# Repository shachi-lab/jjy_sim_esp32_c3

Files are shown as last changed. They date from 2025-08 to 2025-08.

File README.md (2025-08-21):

# 📡 JJY Simulator for ESP32-C3

電波時計の補正信号をESP32-C3で自作！
NTPから取得した正確な時刻をもとに、40kHz / 60kHz のJJY信号をPWM出力で模倣する、ミニJJYシミュレーターです。

## 🛠 特徴

- ESP32-C3 + Arduino によるコンパクトな構成
- Wi-Fi設定はボタンひとつで簡単APモード
- OLEDに現在時刻を表示
- PWM出力は GPIO10 から
- JJY 40kHz（東日本）/ 60kHz（西日本）を切り替え可能
- 出力信号は基板内蔵の簡易アンテナから放射

<a href="./images/jjy_sim_board_w800.jpg">
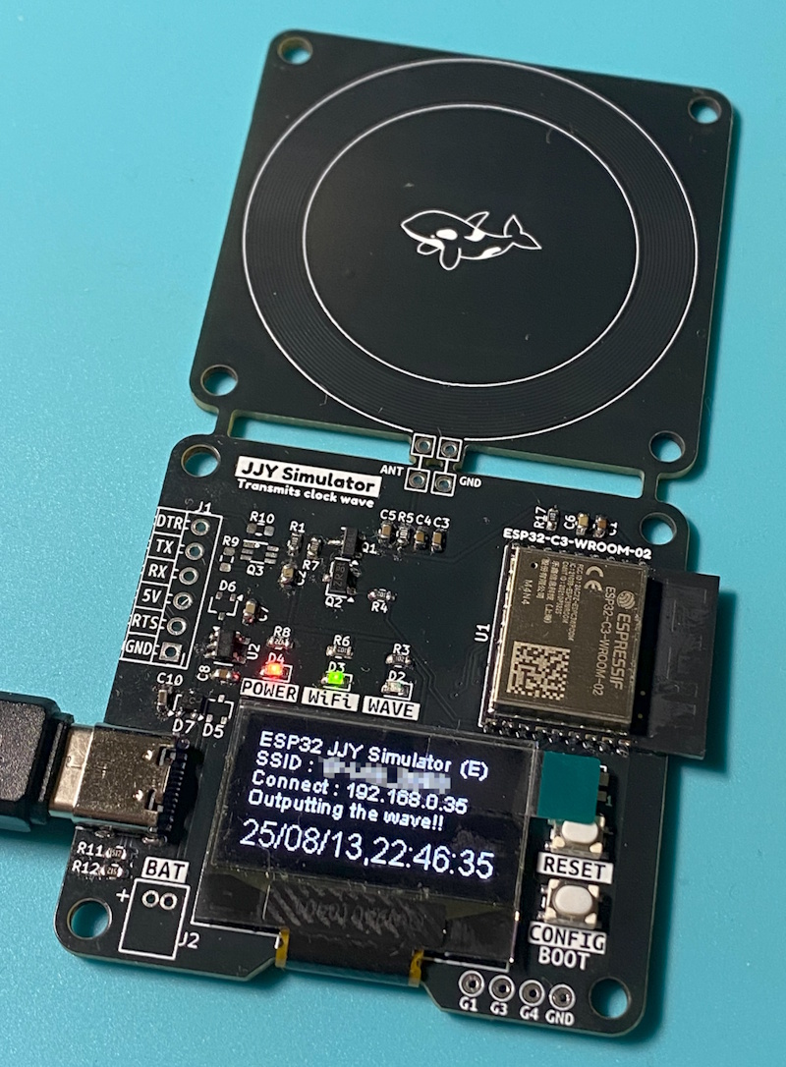
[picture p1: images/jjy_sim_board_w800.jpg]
JJYシミュレーター
</a><br/>

## ⚙️ 使用方法

### 1. コンパイル・書き込み

1. Arduino IDE で ESP32ボードを有効にする  
   - ボードマネージャURL：`https://dl.espressif.com/dl/package_esp32_index.json`
   - 対象ボード：**ESP32-C3 Dev Module**

2. 必要なライブラリをインストールする  
   - [WiFiManager](https://github.com/tzapu/WiFiManager)（バージョン 2.0.17 推奨）
   - [ESP8266 and ESP32 OLED driver for SSD1306 displays](https://github.com/ThingPulse/esp8266-oled-ssd1306)（バージョン 4.6.0 推奨）

   ※ Arduino IDE の「ライブラリを管理」メニューからインストール可能です。

3. `JJY_Sim_ESP32_C3.ino` を開き、必要に応じて以下を編集：
   - `#define JJY_TYPE 0` → `0: 40kHz`, `1: 60kHz`

4. 書き込みポートとボード設定を確認して、コンパイル＆アップロード

> 💡 補足：
> ESP32-C3は、外付けのUSBシリアルICを使わず、チップ内蔵の**ネイティブUSB-UART**機能で書き込み・シリアル通信を行います。
> 一部の環境（特にWindows）では、デバイス認識のために**Espressif提供のUSBドライバ**が必要になる場合があります。

- ドライバDLページ 👉 https://www.espressif.com/en/support/download/other-tools

>⚠️ 初回起動について
> プログラムを書き込んだ直後の「初回起動」では、内部FLASHにファイルシステムを構築する処理が行われます。  
> このため、数十秒ほど反応がなく「ハングしたように見える」場合があります。  
> 完了すると自動的に再起動し、以降は通常通りすぐに動作しますが、再起動しない場合は、RESETボタンでリセットしてください。

### 2. Wi-Fi設定

- 電源投入 or リセット後、5秒以内に CONFIGスイッチを押す
- `ESP32_XXXXXXXX` というAPが起動（パスキー：`password`）
- スマホやPCから接続 → キャプティブポータルでSSID/パスキーを設定

### 3. 動作確認

- 電源投入 or リセット後、5秒間放置すると、WiFiのAPに接続しに行きます。
- APに接続すると、NTPサーバーから時刻を取得します。
- OLEDに現在時刻が表示され、0秒からPWMでJJY信号出力開始
- 電波時計の「受信ボタン」を押して、近くに置いておくだけ！

## 🔌 ピンアサイン（主なもの）

| 機能 | GPIO | 備考 |
|---|---|---|
| JJY PWM出力 | 10 | 変調された信号を出力 |
| CONFIGスイッチ | 9 | Wi-Fi設定用（**BOOTピンと兼用**） |
| ACT LED | 5 | 動作中LED |
| IND LED | 0 | 状態表示用LED（共用可） |
| OLED Reset | 2 | OLEDモジュールリセット |
| OLED SDA|7| OLED I2C データー|
| OLED SCL |6|OLED I2C クロック|

## 🧾 ファイル構成

```
JJY_Sim_ESP32_C3.ino       // メインスケッチ
wire_compat.h              // ESP32-C3 用の I2C バス互換ヘッダ
```

## 📎 依存ライブラリ

- [WiFiManager](https://github.com/tzapu/WiFiManager)
- [ESP8266 and ESP32 OLED driver](https://github.com/ThingPulse/esp8266-oled-ssd1306)

## 🔗 関連リンク

- ブログ記事（詳細解説＋ケースや基板配布）  
  👉 https://blog.shachi-lab.com/033_jjy_simulator/

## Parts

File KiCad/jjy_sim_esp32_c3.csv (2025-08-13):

Reference | Value | Footprint | Qty
C1,C3,C4,C5,C9 | 0.1u | Capacitor SMD 1608 | 5
C2,C7,C10,C11,C12,C13,C14 | 1u | Capacitor SMD 1608 | 7
C6 | 10u | Capacitor SMD 1608 | 1
C8 | 0.22u | Capacitor SMD 1608 | 1
C15,C16 | 4.7u | Capacitor SMD 1608 | 2
D1 | SK6812MINI | SK6812MINI | 1
D2 | LED (B) | LED SMD 1608 | 1
D3 | LED (YG) | LED SMD 1608 | 1
D4 | LED (R) | LED SMD 1608 | 1
D5,D6 | SB1003M3 | SMD SOT-323/SC-70 | 2
D7 | SB1003M3 | SMD SOT-323/SC-70 | 1
J1 | UART | PinHeader_1x06_P2.54mm_Horizontal | 1
J2 | BAT | JST_PH_B2B-PH-K_1x02_P2.00mm_Vertical | 1
P1 | USB_C_Plug_USB2.0 | 5077CR-16SMC2-BK-TR | 1
Q1 | BSS84 | SMD SOT-23 | 1
Q2 | 2PD601AR | SMD SC-59 | 1
Q3 | HN1C01FU-GR | 2-2J1A | 1
R1,R14,R15,R17 | 10k | Resistor SMD 1608 | 4
R9,R10 | 10k | Resistor SMD 1608 | 2
R2,R3,R4 | 1k | Resistor SMD 1608 | 3
R5 | 100 | Resistor SMD 1608 | 1
R6 | 2.2k | Resistor SMD 1608 | 1
R7 | 100k | Resistor SMD 1608 | 1
R8 | 4.7k | Resistor SMD 1608 | 1
R11,R12 | 5.1k | Resistor SMD 1608 | 2
R13 | 0 | Resistor SMD 1608 | 1
R16 | 390k | Resistor SMD 1608 | 1
SW1 | RESET | SKRPACE010 | 1
SW2 | CONFIG | SKRPACE010 | 1
U1 | ESP32-C3-WROOM-02 | ESP32-C3-WROOM-02 | 1
U2 | RT9193-33GB | SMD SOT-23-5 | 1
U3 | UG-2864HL | UG-2864-FPC | 1

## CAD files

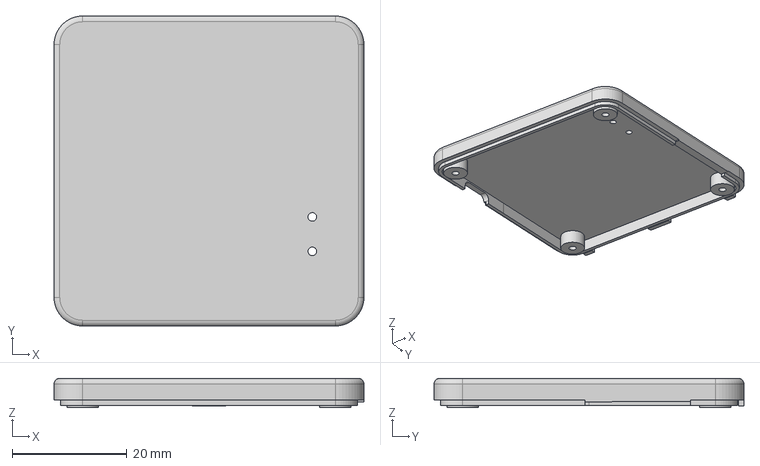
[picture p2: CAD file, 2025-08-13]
3DPrint/ESP32_C3_JJY_SIM_Top_v2.step
54.0 x 54.0 x 5.10 mm

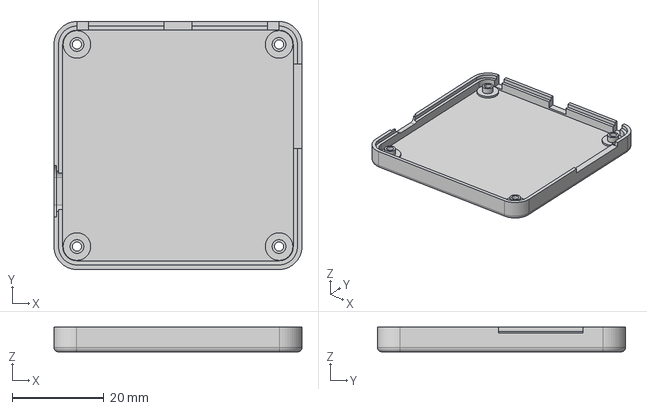
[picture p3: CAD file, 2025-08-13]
3DPrint/ESP32_C3_JJY_SIM_Bottom_v2.step
54.0 x 54.0 x 5.40 mm

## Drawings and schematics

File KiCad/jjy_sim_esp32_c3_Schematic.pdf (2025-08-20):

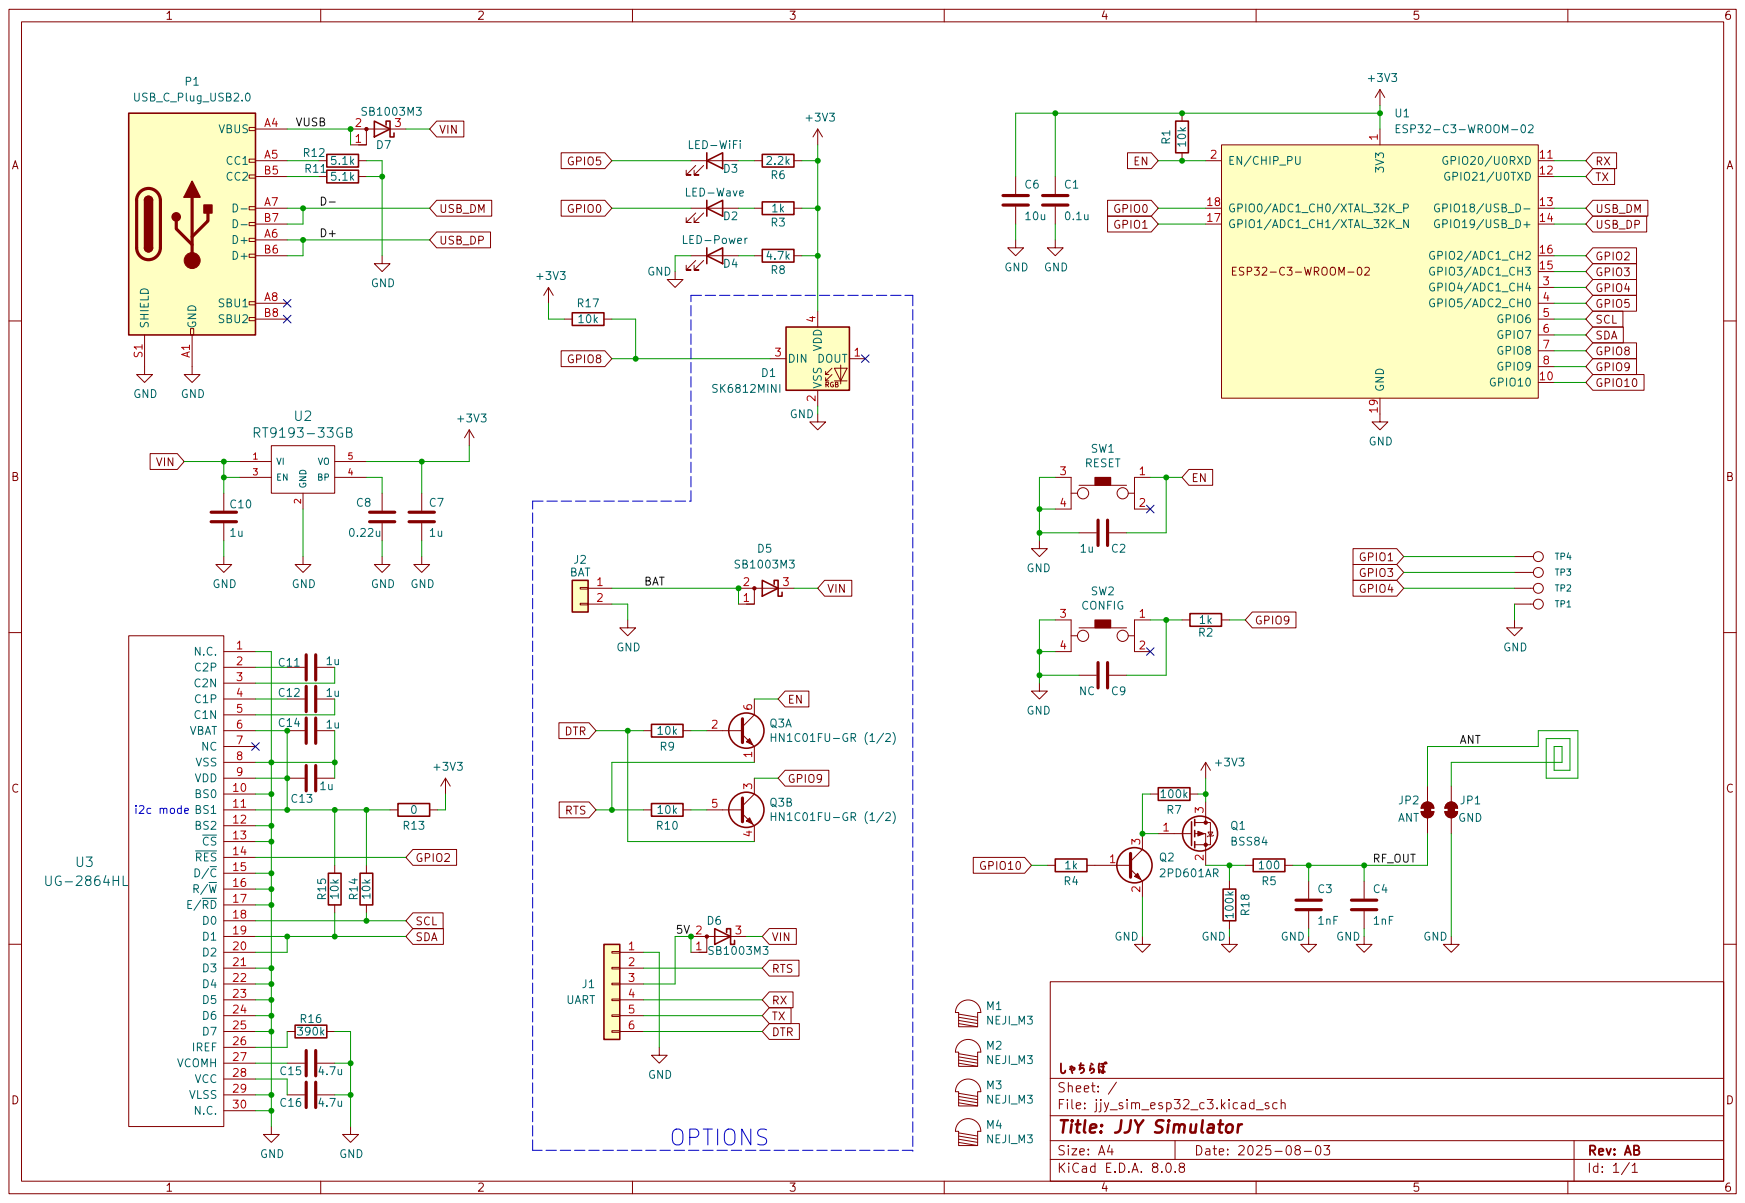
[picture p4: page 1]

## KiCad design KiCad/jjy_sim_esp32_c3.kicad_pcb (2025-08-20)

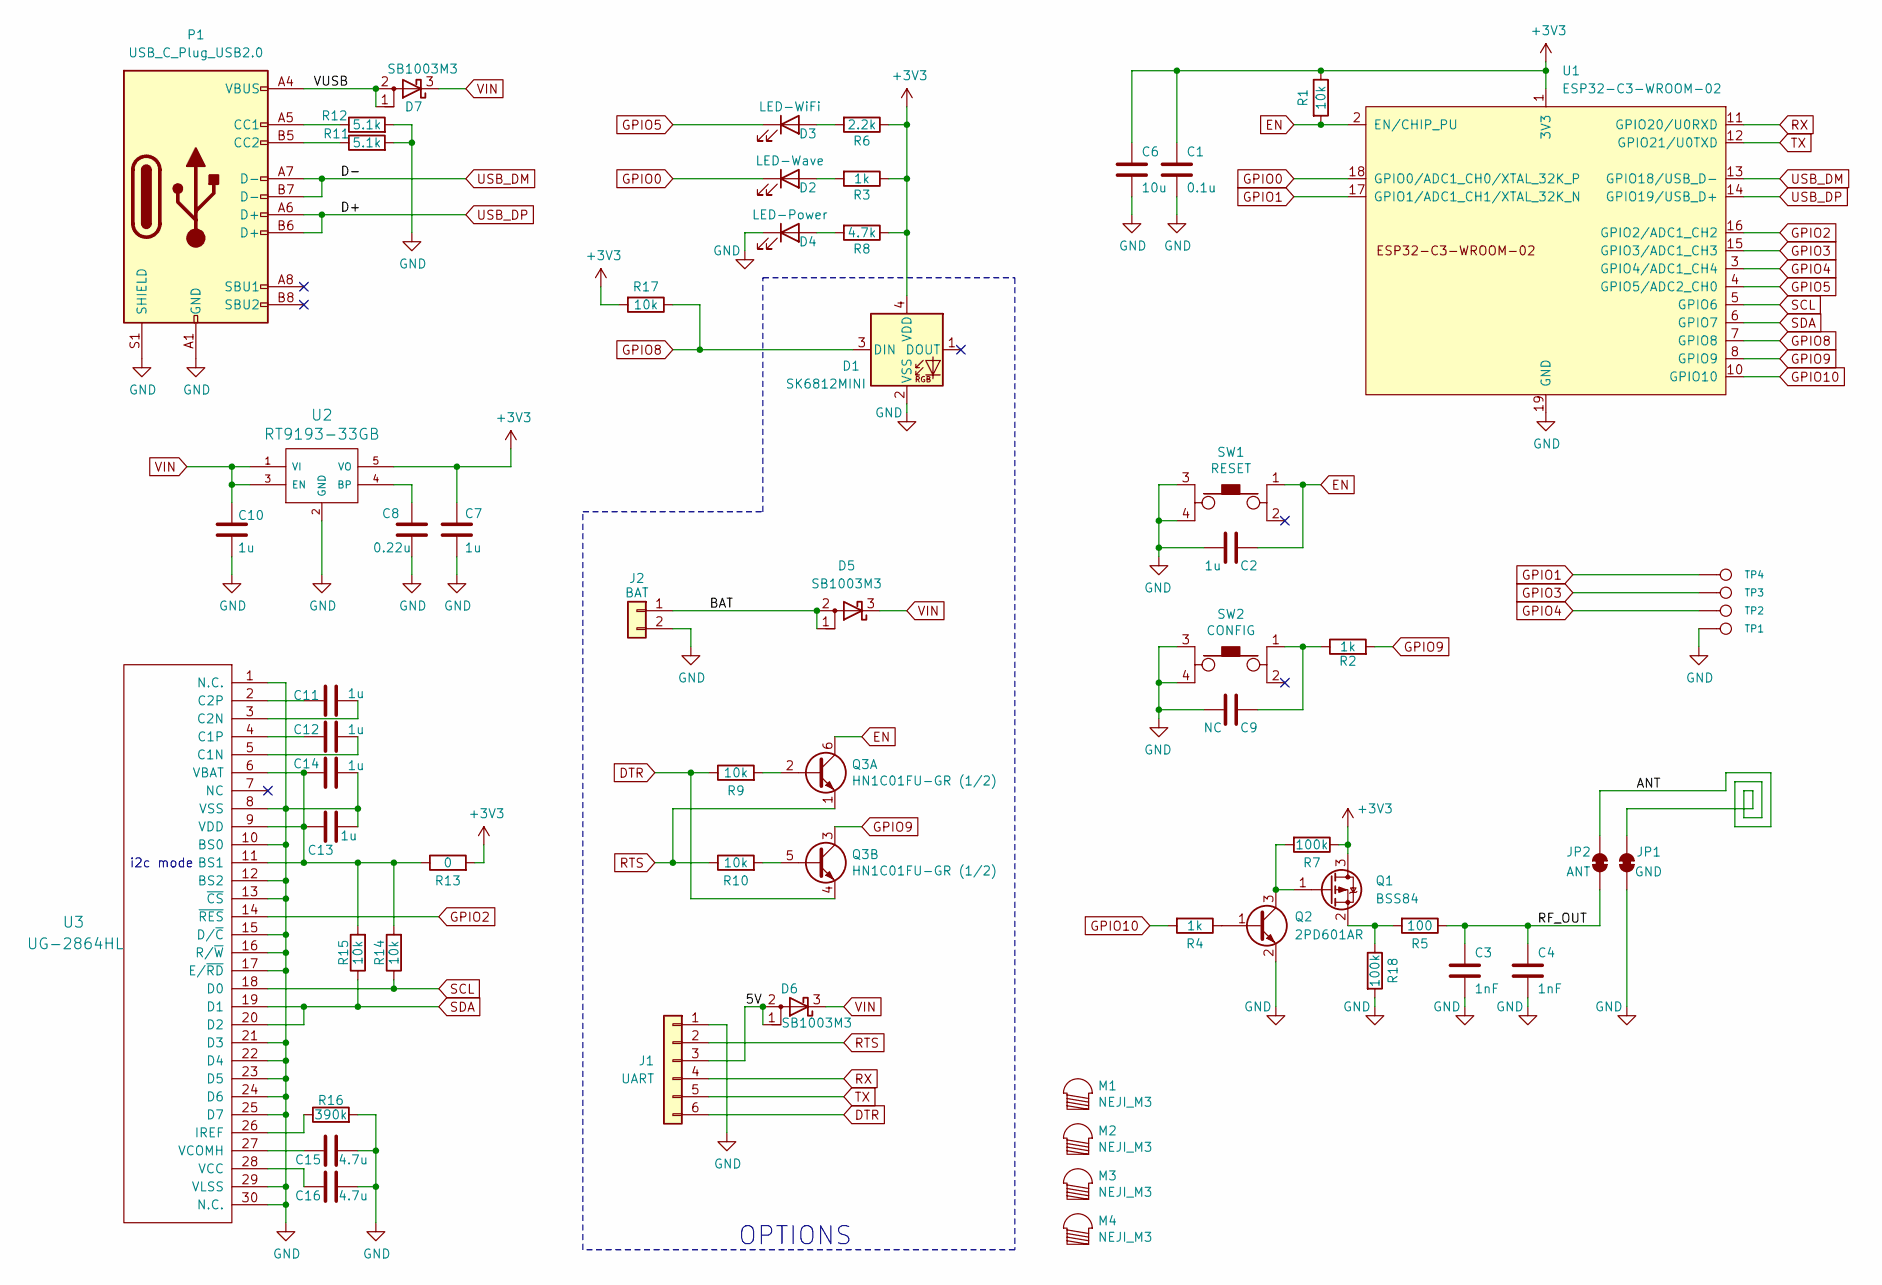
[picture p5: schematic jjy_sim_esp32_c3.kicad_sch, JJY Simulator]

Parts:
C1: 0.1u; C_0603_1608Metric
C2, C7, C10, C11, C12, C13, C14: 1u; C_0603_1608Metric
C3, C4: 1nF; C_0603_1608Metric
C6: 10u; C_0603_1608Metric
C8: 0.22u; C_0603_1608Metric
C9: NC; C_0603_1608Metric
C15, C16: 4.7u; C_0603_1608Metric
D1: SK6812MINI; LED_SK6812MINI_PLCC4_3.5x3.5mm_P1.75mm
D2: LED-Wave; LED_0603_1608Metric
D3: LED-WiFi; LED_0603_1608Metric
D4: LED-Power; LED_0603_1608Metric
D5, D6, D7: SB1003M3; SOT-323_SC-70
J1: UART; PinHeader_1x06_P2.54mm_Horizontal
J2: BAT; JST_PH_B2B-PH-K_1x02_P2.00mm_Vertical
JP1: GND; Jumper-2_TH_3.81mm
JP2: ANT; Jumper-2_TH_3.81mm
M1, M2, M3, M4: NEJI_M3; HOLE-3M_55
P1: USB_C_Plug_USB2.0; 5077CR-16SMC2-BK-TR
Q1: BSS84; SOT-23
Q2: 2PD601AR; SC-59
Q3: HN1C01FU-GR (1/2); 2-2J1A
R1, R9, R10, R14, R15, R17: 10k; R_0603_1608Metric
R2, R3, R4: 1k; R_0603_1608Metric
R5: 100; R_0603_1608Metric
R6: 2.2k; R_0603_1608Metric
R7, R18: 100k; R_0603_1608Metric
R8: 4.7k; R_0603_1608Metric
R11, R12: 5.1k; R_0603_1608Metric
R13: 0; R_0603_1608Metric
R16: 390k; R_0603_1608Metric
SW1: RESET; SKRPACE010
SW2: CONFIG; SKRPACE010
TP1, TP2, TP3, TP4: TP; TestPoint_THTPad_D1.5mm_Drill0.7mm
U1: ESP32-C3-WROOM-02
U2: RT9193-33GB; SOT-23-5
U3: UG-2864HL; UG-2864-FPC

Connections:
+3V3: C1.1, C6.1, C7.1, D1.4 (VDD), Q1.3 (D), R1.1, R3.1, R6.1, R7.1, R8.1, R13.2, R17.2, U1.1 (3V3), U2.5 (VO)
/5V: D6.1 (A), D6.2 (A), J1.3
/ANT: JP1.2 (B), JP2.2 (B)
/BAT: D5.1 (A), D5.2 (A), J2.1
/RF_OUT: C3.1, C4.1, JP2.1 (A), R5.1
/VUSB: D7.1 (A), D7.2 (A), P1.A4 (VBUS), P1.A9 (VBUS), P1.B4 (VBUS), P1.B9 (VBUS)
DTR: J1.6, Q3.4 (E2), R9.1
EN: C2.2, Q3.6 (C1), R1.2, SW1.1, U1.2 (EN/CHIP_PU)
GND: C1.2, C2.1, C3.2, C4.2, C6.2, C7.2, C8.2, C9.1, C10.2, C13.2, C14.2, C15.2, C16.2, D1.2 (VSS), D4.1 (K), J1.1, J2.2, JP1.1 (A), P1.A1 (GND), P1.A12 (GND), P1.B1 (GND), P1.B12 (GND), P1.S1 (SHIELD), Q2.2 (E), R11.2, R12.2, R16.2, R18.2, SW1.3, SW1.4, SW2.3, SW2.4, TP1.1, U1.9 (GND), U1.19 (GND), U2.2 (GND), U3.1 (N.C.), U3.8 (VSS), U3.10 (BS0), U3.12 (BS2), U3.13 (~CS), U3.15 (D/~C), U3.16 (R/~W), U3.17 (E/~RD), U3.21 (D3), U3.22 (D4), U3.23 (D5), U3.24 (D6), U3.25 (D7), U3.29 (VLSS), U3.30 (N.C.)
GPIO0: D2.1 (K), U1.18 (GPIO0/ADC1_CH0/XTAL_32K_P)
GPIO1: TP4.1, U1.17 (GPIO1/ADC1_CH1/XTAL_32K_N)
GPIO2: U1.16 (GPIO2/ADC1_CH2), U3.14 (~RES)
GPIO3: TP3.1, U1.15 (GPIO3/ADC1_CH3)
GPIO4: TP2.1, U1.3 (GPIO4/ADC1_CH4)
GPIO5: D3.1 (K), U1.4 (GPIO5/ADC2_CH0)
GPIO8: D1.3 (DIN), R17.1, U1.7 (GPIO8)
GPIO9: Q3.3 (C2), R2.2, U1.8 (GPIO9)
GPIO10: R4.2, U1.10 (GPIO10)
unnamed: C9.2, R2.1, SW2.1
unnamed: D2.2 (A), R3.2
unnamed: D3.2 (A), R6.2
unnamed: D4.2 (A), R8.2
unnamed: P1.A5 (CC1), R12.1
unnamed: P1.B5 (CC2), R11.1
unnamed: Q1.1 (G), Q2.3 (C), R7.2
unnamed: Q1.2 (S), R5.2, R18.1
unnamed: Q2.1 (B), R4.1
unnamed: Q3.2 (B1), R9.2
unnamed: Q3.5 (B2), R10.2
unnamed: C8.1, U2.4 (BP)
unnamed: C13.1, C14.1, R13.1, R14.2, R15.2, U3.6 (VBAT), U3.9 (VDD), U3.11 (BS1)
unnamed: C12.2, U3.5 (C1N)
unnamed: C12.1, U3.4 (C1P)
unnamed: C11.2, U3.3 (C2N)
unnamed: C11.1, U3.2 (C2P)
unnamed: R16.1, U3.26 (IREF)
unnamed: C16.1, U3.28 (VCC)
unnamed: C15.1, U3.27 (VCOMH)
RTS: J1.2, Q3.1 (E1), R10.1
RX: J1.4, U1.11 (GPIO20/U0RXD)
SCL: R14.1, U1.5 (GPIO6), U3.18 (D0)
SDA: R15.1, U1.6 (GPIO7), U3.19 (D1), U3.20 (D2)
TX: J1.5, U1.12 (GPIO21/U0TXD)
USB_DM: P1.A7 (D-), P1.B7 (D-), U1.13 (GPIO18/USB_D-)
USB_DP: P1.A6 (D+), P1.B6 (D+), U1.14 (GPIO19/USB_D+)
VIN: C10.1, D5.3 (K), D6.3 (K), D7.3 (K), U2.1 (VI), U2.3 (EN)

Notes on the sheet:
OPTIONS
i2c mode

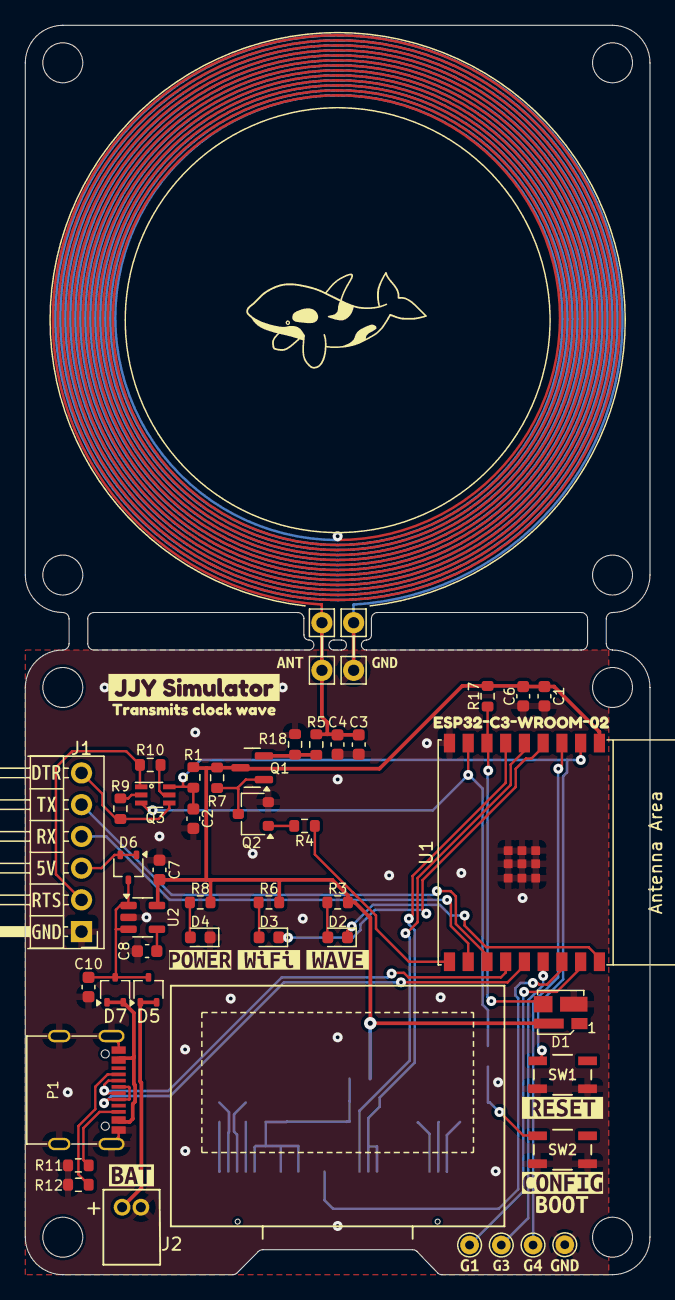
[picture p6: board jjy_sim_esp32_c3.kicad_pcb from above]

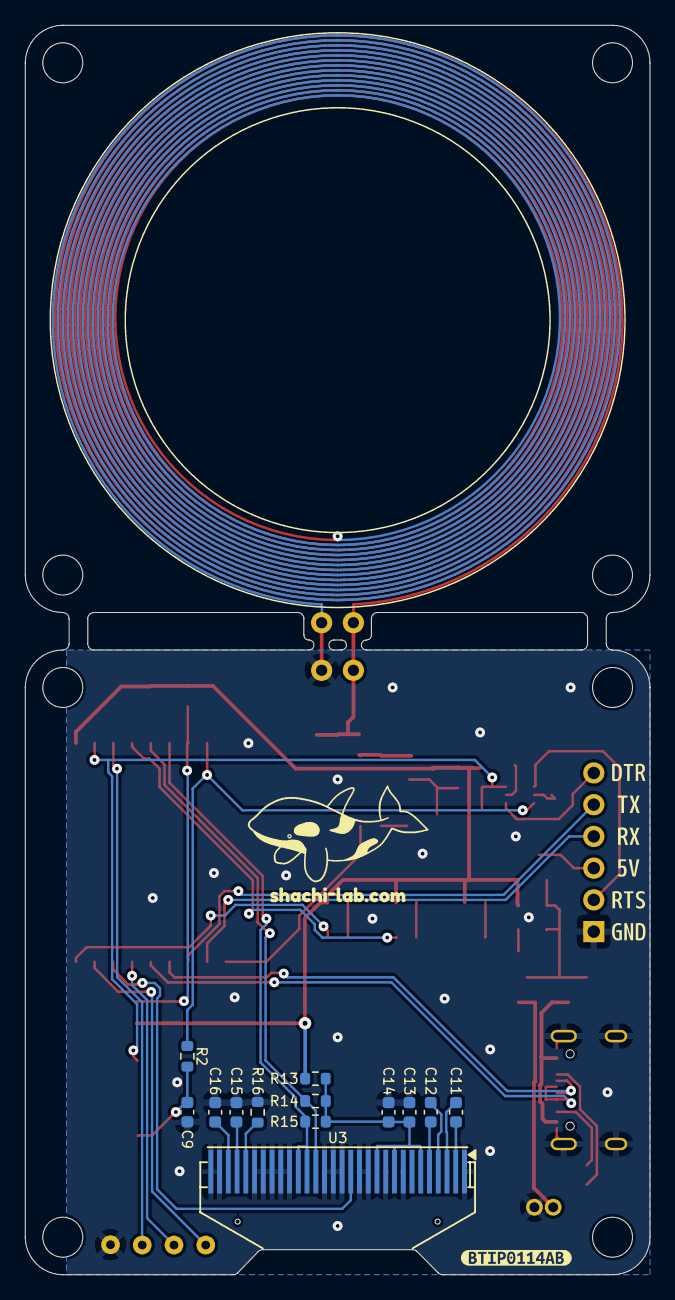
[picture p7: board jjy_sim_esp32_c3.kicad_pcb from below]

Board: 2 copper layers, 50.0 x 100.0 mm, 91 parts (21 on the bottom side), 46 nets.

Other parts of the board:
kibuzzard-5: G***; kibuzzard-665A8DD6
kibuzzard-7: G***; kibuzzard-664968E2
kibuzzard-9: G***; kibuzzard-6646C6AC
kibuzzard-13: G***; kibuzzard-6649687C
kibuzzard-665ABDD7: G***; kibuzzard-665ABDD7
kibuzzard-665AC270: G***; kibuzzard-665AC270
kibuzzard-665B35A8: G***; kibuzzard-665B35A8
kibuzzard-665B35AE: G***; kibuzzard-665B35AE
kibuzzard-665B35C9: G***; kibuzzard-665B35C9
kibuzzard-665B357F: G***; kibuzzard-665B357F
kibuzzard-665B3587: G***; kibuzzard-665B3587
kibuzzard-665BB8A3: G***; kibuzzard-665BB8A3
kibuzzard-665BB8AA: G***; kibuzzard-665BB8AA
kibuzzard-665BB8B1: G***; kibuzzard-665BB8B1
kibuzzard-665BB88E: G***; kibuzzard-665BB88E
kibuzzard-665BB89D: G***; kibuzzard-665BB89D
kibuzzard-665BBA5E: G***; kibuzzard-665BBA5E
kibuzzard-665BBA6E: G***; kibuzzard-665BBA6E
kibuzzard-665BBA64: G***; kibuzzard-665BBA64
kibuzzard-665BBA69: G***; kibuzzard-665BBA69
kibuzzard-665BBA79: G***; kibuzzard-665BBA79
kibuzzard-667C13C8: G***; kibuzzard-667C13C8
kibuzzard-669B6BC9: G***; kibuzzard-669B6BC9
kibuzzard-669B6D24: G***; kibuzzard-669B6D24
kibuzzard-669B6DC4: G***; kibuzzard-669B6DC4
kibuzzard-669B16B9: G***; kibuzzard-669B16B9
kibuzzard-669B4532: G***; kibuzzard-669B4532
kibuzzard-669B8430: G***; kibuzzard-669B8430
kibuzzard-669B8438: G***; kibuzzard-669B8438
kibuzzard-66603A24: G***; kibuzzard-66603A24

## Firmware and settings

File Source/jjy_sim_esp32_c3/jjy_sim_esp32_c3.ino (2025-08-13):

/*
 * JJY 送信 シミュレーター
 * 「ESP32-C3」
 * 
 * 追加ボードマネージャ
 *   https://dl.espressif.com/dl/package_esp32_index.json
 *   ボード : ESP32C3 Dev Module
 *
 * 使用するライブラリ
 *   ThingPulse / ESP8266_and_ESP32_OLED_driver : v 2.0.17 
 *     https://github.com/ThingPulse/esp8266-oled-ssd1306
 *   tzapu / WiFiManager : v 4.6.0
 *     https://github.com/tzapu/WiFiManager
 *
 */
#include <WiFi.h>
#include <time.h>
#include "wire_compat.h"
#include <SSD1306Wire.h>
#include <OLEDDisplayUi.h>
#include <WiFiManager.h>
#include <FS.h>
#include <SPIFFS.h>

#define FORMAT_SPIFFS_IF_FAILED true
#define FILE_NAME         "/JJY_TYPE.DAT"

#define JST               (9*3600)
#undef  BUILTIN_LED
#define BUILTIN_LED       0       // GPIO0
#define IND_LED           BUILTIN_LED
#define ACT_LED           5       // GPIO5
#define LED_ON            0
#define LED_OFF           1
#define LED_BLINK         2

#define CONFIG_PIN        9       // GPIO9
#define OLED_RES_PIN      2       // GPIO2
#define PWM_PIN           10      // GPIO10
#define SCL               6       // GPIO6
#define SDA               7       // GPIO5

#define I2CADR            0x3c

#define JJY_FREQ_EAST     40000
#define JJY_FREQ_WEST     60000
#define JJY_STR_EAST      "(E)"
#define JJY_STR_WEST      "(W)"
#define JJY_TYPE_STR(type)  (!type ? JJY_STR_EAST : JJY_STR_WEST)
#define JJY_TYPE_FREQ(type) (!type ? JJY_FREQ_EAST : JJY_FREQ_WEST)

#define CONFIG_WAIT_TIME  5000    // msec
#define CONFIG_WAIT_TICK  100     // msec

#define PWM_BITS          7
#define PWN_RANGE         ((1 << PWM_BITS) - 1)
#define PWM_DUTY_OFF      0 
#define PWM_DUTY_ON       (PWN_RANGE / 2)

#define JJY_T_BIT0        800
#define JJY_T_BIT1        500
#define JJY_T_PM          200

#define JJY_BIT_PMn       -1
#define JJY_BIT_PM0       -2

const char* Potal_pass = "password";
const char* Version_str = "Version 1.00.0";

String WiFi_ssid = "invalid";
String WiFi_pass = "invalid";
String WiFi_time = "";
String WiFi_ip   = "";
char timeNowStr[64] = "";

SSD1306Wire display(I2CADR, SDA, SCL);  

WiFiManager wm; // global wm instance
WiFiManagerParameter custom_field; // global param ( for non blocking w params )

bool JJY_type = false;
int JJY_freq = JJY_FREQ_EAST;
String JJY_str = JJY_STR_EAST;
int config_wait_remain = 0;

/*
* 初期化
*/
void setup() {

  bool conn_flag = false;

  pinMode(IND_LED, OUTPUT);  
  pinMode(ACT_LED, OUTPUT);
  led_blink(IND_LED, LED_ON);
  led_blink(ACT_LED, LED_ON);
  delay(500);

  Serial.begin(115200);
  Serial.println();
  Serial.println("Start JJY Sim / ESP32-C3");

  if (!SPIFFS.begin(FORMAT_SPIFFS_IF_FAILED)) {
    go_reboot("SPIFFS Mount Failed");
  } else {
    JJY_type = get_JJY_type();
    if ( JJY_type ) {
      JJY_freq = JJY_FREQ_WEST;
      JJY_str = JJY_STR_WEST;
    }
  }
  Serial.println("JJY_FREQ = " + String(JJY_freq) + JJY_str ); 

  disp_screen(0);

  pinMode(CONFIG_PIN, INPUT_PULLUP);  
  led_blink(IND_LED, LED_OFF);
  led_blink(ACT_LED, LED_OFF);

  WiFi.mode(WIFI_STA); // explicitly set mode, esp defaults to STA+AP  

  led_blink(IND_LED, LED_ON);

  for(int i = CONFIG_WAIT_TIME/CONFIG_WAIT_TICK; i; i-- ) {
    config_wait_remain = i / (1000/CONFIG_WAIT_TICK) + 1;
    disp_screen(-1);

    delay(CONFIG_WAIT_TICK);
    if(digitalRead(CONFIG_PIN) != LOW) continue;

    disp_screen(-2);
    led_blink(IND_LED, LED_BLINK);
    Serial.println("Enter to CONFIG mode");

    config_mode_setup();

    if (!wm.startConfigPortal()) {
      go_reboot("failed to connect / timeout");
    }
    conn_flag = true;
    break;
  }

  WiFi_ssid = wm.getWiFiSSID(!conn_flag);
  WiFi_pass = wm.getWiFiPass(!conn_flag);
  Serial.println(WiFi_ssid);
  Serial.println(WiFi_pass);

  disp_screen(1);
  led_blink(IND_LED, LED_OFF);

  if( !conn_flag ) {
    Serial.println("Connecting....");
    led_blink(ACT_LED, LED_BLINK);

    if(!wm.autoConnect()) {
      go_reboot("Failed to connect");
    } 
  }

  if( WiFi.status() == WL_CONNECTED ){

    conn_flag = true;
    Serial.println("connected...");

//  WiFi_ssid = WiFi.SSID();
//  WiFi_pass = WiFi.psk();
    Serial.print  ("IP Address:");
    Serial.println(WiFi.localIP());

    disp_screen(2);  
    led_blink(ACT_LED, LED_ON);

  }else
  { 
    go_reboot("Connect timeout.");
  }

  configTime( JST, 0, "ntp.nict.jp", "ntp.jst.mfeed.ad.jp");

  ledcAttach(PWM_PIN, JJY_freq, PWM_BITS);
}

/*
 * 
 */
void loop() {
  get_ntp_time();
}

void go_reboot(String text)
{
  led_blink(ACT_LED, LED_ON);
  led_blink(IND_LED, LED_ON);
  Serial.println(text);
  Serial.println("reboot!!");
  disp_screen(3);
  delay(3000);
  led_blink(ACT_LED, LED_OFF);
  led_blink(IND_LED, LED_OFF);

  //reset and try again, or maybe put it to deep sleep
  ESP.restart();
  delay(5000);
}

/*
 * 
 */
void led_blink(uint8_t pin, uint8_t mode)
{
  static bool attached[16] = { 0 };
  if( mode == LED_BLINK ) {
    if( !attached[pin] ) ledcAttach(pin, 4, 14);
    attached[pin] = true;
    ledcWrite(pin, 8192);
  } else {
    if( attached[pin] ) ledcDetach(pin);
    attached[pin] = false;
    digitalWrite(pin, mode == LED_OFF);
  }
}

/*
 * 
 */
void disp_screen( int mode )
{
  if(mode == 0) {
    pinMode(OLED_RES_PIN, OUTPUT); 
    digitalWrite(OLED_RES_PIN, 0);
    delay(10);
    digitalWrite(OLED_RES_PIN, 1);

    // Initialising the UI will init the display too.
    display.init();
    display.flipScreenVertically();
  }
  display.clear();
  display.setFont(ArialMT_Plain_10);
  String title = "ESP32 JJY Simulator  " + JJY_str;
  display.drawString( 0,  0, title );

  if( mode == -1 ){
    display.drawString( 0, 10, Version_str );    
    display.drawString( 0, 20, "Waiting for CONFIG" );
    display.drawString( 0, 30, String(config_wait_remain) + " sec left" );
  }
  if( mode == -2 ){  
    display.drawString( 0, 10, "Enter to CONFIG mode" );
  }

  if( mode > 0 ) {
    display.drawString( 0, 10, "SSID : " + WiFi_ssid );
  }
  if( mode == 1 ) {
    display.drawString( 0, 20, "Connecting..." );
  } else
  if( mode == 2 ) {
      display.drawString( 0, 20, "Connect timeout");
      display.drawString( 0, 30, "Reboot now!!" );
  } else
  if( mode > 2 ) {
      display.drawString( 0, 20, "Connect : " + WiFi.localIP().toString());
  }
  if( mode == 5 ){
    display.drawString( 0, 30, "Waiting for just min" );
  } else
  if( mode > 5 ) {
    display.drawString( 0, 30, "Outputting the wave!!" );
  }
  if( mode == 4 ) {
    display.drawString( 0, 30, "Waiting to get time");
  } else
  if( mode > 4 ) {
    display.setFont(ArialMT_Plain_16);
    display.drawString( 0, 45, timeNowStr);
  }
  display.display();
}

/*
 * 
 */
struct tm *get_time_now()
{
  static time_t time_last = 0;

  time_t now = time(NULL);
  if( time_last == now )  return NULL;
  time_last = now;

  struct tm *tm = localtime( &time_last );
  if( tm == NULL ) return NULL;

  if( tm->tm_year < 100 )
  {
      timeNowStr[0] = '\0';
      return tm;
  }
  tm->tm_year -= 100;
  sprintf(timeNowStr, "%02d/%02d/%02d,%02d:%02d:%02d",
    tm->tm_year, tm->tm_mon+1, tm->tm_mday, tm->tm_hour, tm->tm_min, tm->tm_sec);

  return tm;
}

/*
 * 
 */
 void get_ntp_time()
{
  static int radio_output_stat = 0;
  static int last_min = 99;

  struct tm *tm;
  tm = get_time_now();
  if ( tm == NULL ) return; 

  if ( timeNowStr[0] == '\0' ) {
      Serial.printf(".");
      disp_screen(4);
      return;
  }

  disp_screen(5 + radio_output_stat);

  if( tm->tm_sec != 0 ) return;
  if( tm->tm_min == last_min ) return;
  last_min = tm->tm_min;

  Serial.println();
  Serial.printf("JST=%s > ", timeNowStr);

  radio_output_stat = 1;

  jjy_output( tm );

  led_blink(IND_LED, LED_ON);
}

/*
 * 
 */
void jjy_put_bit( int flag )
{
  int t_on, t_off;
  char ch;

  if( flag < 0 ){
    t_on = JJY_T_PM;
    t_off = (flag == JJY_BIT_PM0) ? 100 : 1000 - JJY_T_PM;
    ch = '-';
  }else
  if( flag == 0 )
  {
    t_on = JJY_T_BIT0;
    t_off = 1000 - JJY_T_BIT0;
    ch = '0';
  }else
  {
    t_on = JJY_T_BIT1;
    t_off = 1000 - JJY_T_BIT1;
    ch = '1';
  }
  Serial.write( ch );

  ledcWrite(PWM_PIN, PWM_DUTY_ON);
  digitalWrite(BUILTIN_LED, LED_ON);
  delay( 3 );   
  digitalWrite(BUILTIN_LED, LED_OFF);
  delay( t_on - 3 );
  ledcWrite(PWM_PIN, PWM_DUTY_OFF);
//delay( t_off );

  if ( flag == JJY_BIT_PM0 ){
    delay( t_off );
    return;
  }
  while ( get_time_now() == NULL ) delay(1);
  disp_screen(6);
}

/*
 * 
 */
int get_int_to_bcd( int n )
{
  int res = n % 10;
  res += ((n/ 10)%10)<<4;
  res += ((n/100)%10)<<8;
  return res;
}

/*
 * 
 */
int get_even_parity( int n )
{
  n ^= n >> 8;
  n ^= n >> 4;
  n ^= n >> 2;
  n ^= n >> 1;
  return n & 1;
}

/*
 * 
 */
void jjy_output( struct tm *tm )
{
const int totalDaysOfMonth[] = {0,31,59,90,120,151,181,212,243,273,304,334 };
  int totalDays = totalDaysOfMonth[tm->tm_mon];
  totalDays += tm->tm_mday;
  if(((tm->tm_year & 0x03)==0) && (tm->tm_mon > 2)) totalDays++;

  int mm = get_int_to_bcd( tm->tm_min );
  int hh = get_int_to_bcd( tm->tm_hour );
  int dd = get_int_to_bcd( totalDays );
  int yy = get_int_to_bcd( tm->tm_year % 100 );
  int pa1= get_even_parity( hh );
  int pa2= get_even_parity( mm );
  int ww = tm->tm_wday;

  jjy_put_bit( JJY_BIT_PMn );   // :00 M
  jjy_put_bit( mm & 0x40 );     // :01
  jjy_put_bit( mm & 0x20 );     // :02
  jjy_put_bit( mm & 0x10 );     // :03
  jjy_put_bit( 0 );             // :04
  jjy_put_bit( mm & 0x08 );     // :05
  jjy_put_bit( mm & 0x04 );     // :06
  jjy_put_bit( mm & 0x02 );     // :07
  jjy_put_bit( mm & 0x01 );     // :08
  jjy_put_bit( JJY_BIT_PMn );   // :09 P1
  jjy_put_bit( 0 );             // :10
  jjy_put_bit( 0 );             // :11
  jjy_put_bit( hh & 0x20 );     // :12
  jjy_put_bit( hh & 0x10 );     // :13
  jjy_put_bit( 0 );             // :14
  jjy_put_bit( hh & 0x08 );     // :15
  jjy_put_bit( hh & 0x04 );     // :16
  jjy_put_bit( hh & 0x02 );     // :17
  jjy_put_bit( hh & 0x01 );     // :18
  jjy_put_bit( JJY_BIT_PMn );   // :19 P2
  jjy_put_bit( 0 );             // :20
  jjy_put_bit( 0 );             // :21
  jjy_put_bit( dd & 0x200 );    // :22
  jjy_put_bit( dd & 0x100 );    // :23
  jjy_put_bit( 0 );             // :24
  jjy_put_bit( dd & 0x80 );     // :25
  jjy_put_bit( dd & 0x40 );     // :26
  jjy_put_bit( dd & 0x20 );     // :27
  jjy_put_bit( dd & 0x10 );     // :28
  jjy_put_bit( JJY_BIT_PMn );   // :29 P3
  jjy_put_bit( dd & 0x08 );     // :30
  jjy_put_bit( dd & 0x04 );     // :31
  jjy_put_bit( dd & 0x02 );     // :32
  jjy_put_bit( dd & 0x01 );     // :33
  jjy_put_bit( 0 );             // :34
  jjy_put_bit( 0 );             // :35
  jjy_put_bit( pa1 );           // :36 PA1
  jjy_put_bit( pa2 );           // :37 PA2
  jjy_put_bit( 0 );             // :38 SU1
  jjy_put_bit( JJY_BIT_PMn );   // :39 P4
  jjy_put_bit( 0 );             // :40 SU2
  jjy_put_bit( yy & 0x80 );     // :41
  jjy_put_bit( yy & 0x40 );     // :42
  jjy_put_bit( yy & 0x20 );     // :43
  jjy_put_bit( yy & 0x10 );     // :44
  jjy_put_bit( yy & 0x08 );     // :45
  jjy_put_bit( yy & 0x04 );     // :46
  jjy_put_bit( yy & 0x02 );     // :47
  jjy_put_bit( yy & 0x01 );     // :48
  jjy_put_bit( JJY_BIT_PMn );   // :49 P5
  jjy_put_bit( ww & 0x04 );     // :50
  jjy_put_bit( ww & 0x02 );     // :51
  jjy_put_bit( ww & 0x01 );     // :52
  jjy_put_bit( 0 );             // :53 LS1
  jjy_put_bit( 0 );             // :54 LS2
  jjy_put_bit( 0 );             // :55
  jjy_put_bit( 0 );             // :56
  jjy_put_bit( 0 );             // :57
  jjy_put_bit( 0 );             // :58
  jjy_put_bit( JJY_BIT_PM0 );   // :59 P0
}

/*
 * 
 */
uint8_t get_JJY_type()
{
  uint8_t type = 0;
  File fp = SPIFFS.open(FILE_NAME, FILE_READ);
  if( !fp || fp.isDirectory() ) {
    Serial.println("- failed to open file for reading");
    return type;
  }
  if ( fp.available() ) {
    type = (fp.readString()).toInt();
  }
  fp.close();
  return type;
}

/*
 * 
 */
void put_JJY_type(String type)
{
  File fp = SPIFFS.open(FILE_NAME, FILE_WRITE);
  if( !fp || fp.isDirectory() ) {
    Serial.println("- failed to open file for writting");
    return;
  }
  fp.print( type );
  fp.close();
}

/*
 * 
 */
void config_mode_setup()
{
  static String custom_radio_str = "<br/><label for='radiofreq'>Radio Freq</label><br><input type='radio' name='radiofreq' value='0' ";
  if (!JJY_type)  custom_radio_str += "checked";
  custom_radio_str += "> 40kHz (East)<br><input type='radio' name='radiofreq' value='1' ";
  if (JJY_type)   custom_radio_str += "checked";
  custom_radio_str += "> 60kHz (West)";
  
  new (&custom_field) WiFiManagerParameter(custom_radio_str.c_str()); // custom html input
  wm.addParameter(&custom_field);
  wm.setSaveParamsCallback(saveParamCallback);
  std::vector<const char *> menu = {"wifi","info","param","sep","restart","exit"};
  wm.setMenu(menu);
  // set dark theme
  wm.setClass("invert");

  wm.setConfigPortalTimeout(120);
}

/*
 * 
 */
String getParam(String name)
{
  //read parameter from server, for customhmtl input
  String value;
  if(wm.server->hasArg(name)) {
    value = wm.server->arg(name);
  }
  return value;
}

/*
 * 
 */
void saveParamCallback(){
  Serial.println("[CALLBACK] saveParamCallback fired");
  String para = getParam("radiofreq");
  Serial.println("PARAM radiofreq = " + para);
  put_JJY_type(para);
}

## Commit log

2025-08-13 1st commit
    [ESP32_C3_JJY_SIM_Bottom_v2.step, ESP32_C3_JJY_SIM_Top_v2.step, jjy_sim_esp32_c3.csv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]
2025-08-13 README修正
2025-08-20 C3,C4定数変更、C5をR18に変更
    [jjy_sim_esp32_c3.kicad_pcb, jjy_sim_esp32_c3.kicad_sch]
2025-08-21 READMEに、初回起動時の注意事項を追加
